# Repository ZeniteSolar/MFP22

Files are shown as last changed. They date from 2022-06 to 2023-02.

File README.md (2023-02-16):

# MFP19
**M**ódulo da **F**onte **P**rincipal 2019  
Embarcação Guarapuvu II  
Equipe Zênite Solar  

### Sobre

Este módulo é responsável por fornecer uma tensao fixa e estavel de 18V para alimentaçao dos modulos que estao na rede CAN

### Images
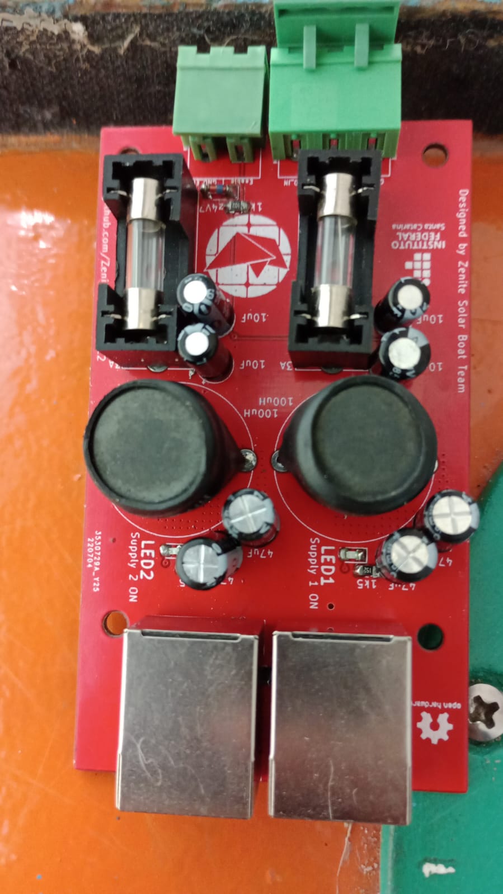
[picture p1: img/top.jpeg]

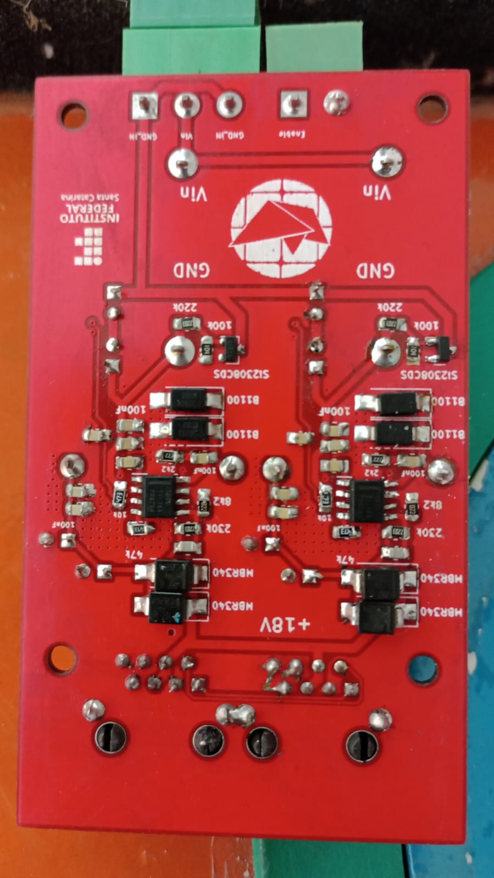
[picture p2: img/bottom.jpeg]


#### Requisitos e Abordagens
1. Fornecer tensao estavel de 18V 
    - Manter a tensao estavel independente da carga (até 3A)
    - Baixo ripple
2. Ser robusta
    - Nao queimar por curto-circuito
    - Nao queimar por sobre temperatura
    - Nao queimar por sobre-carga
    - Resistencia por ruido eletromagnetico e eletrico causados pelos componentes do sistema (motor,MCC...)
3. Eficiencia energetica.
    -Conversor estatico DC/DC chaveado
4. Facilitar o diagnóstico
    - Utilizar LEDs
    
**CI Ultilizado: Conversor LMR16030**
[Datasheet](https://www.ti.com/lit/ds/symlink/lmr16030.pdf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)

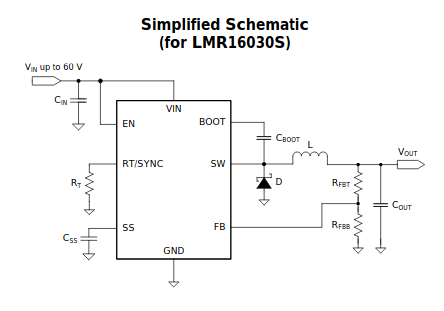
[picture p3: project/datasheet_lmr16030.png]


#### Projeto do Indutor

   -seleção do indutor de saida:



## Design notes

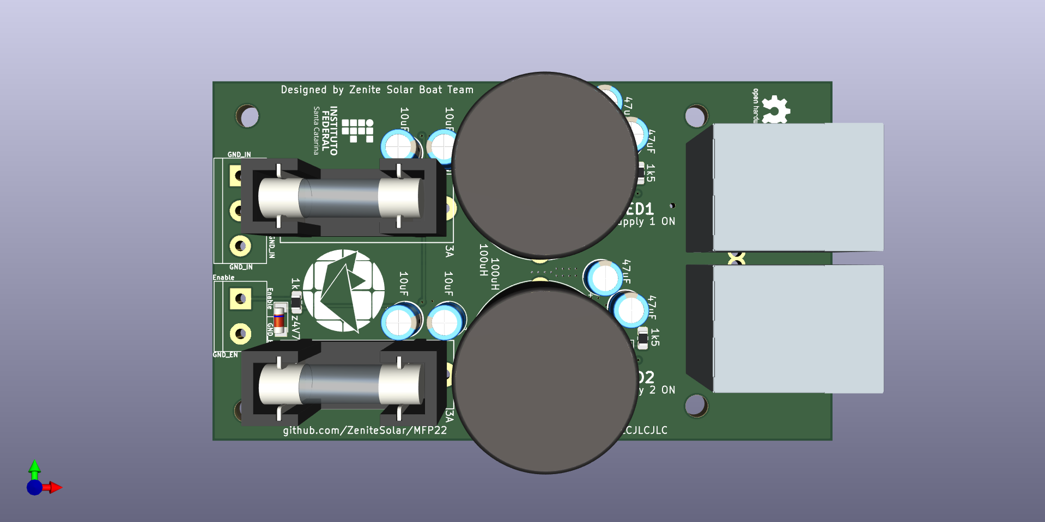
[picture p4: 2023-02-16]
3D/fonte_18V_top.png

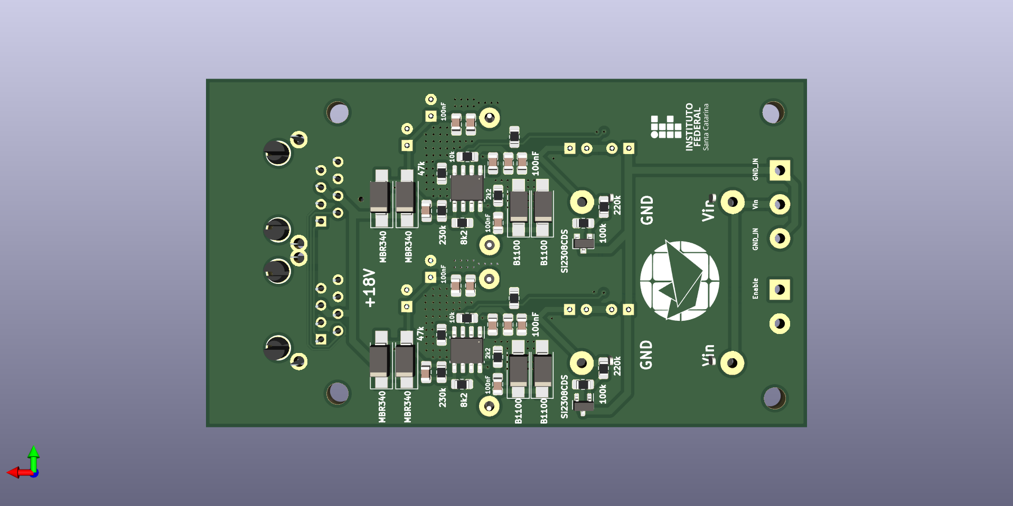
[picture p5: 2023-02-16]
3D/fonte_18V.png

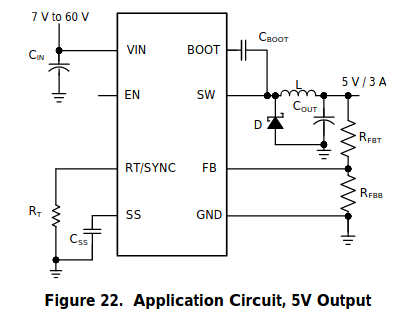
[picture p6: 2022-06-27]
project/ datasheet (Rev A) - lmr16030 pdf(1).png

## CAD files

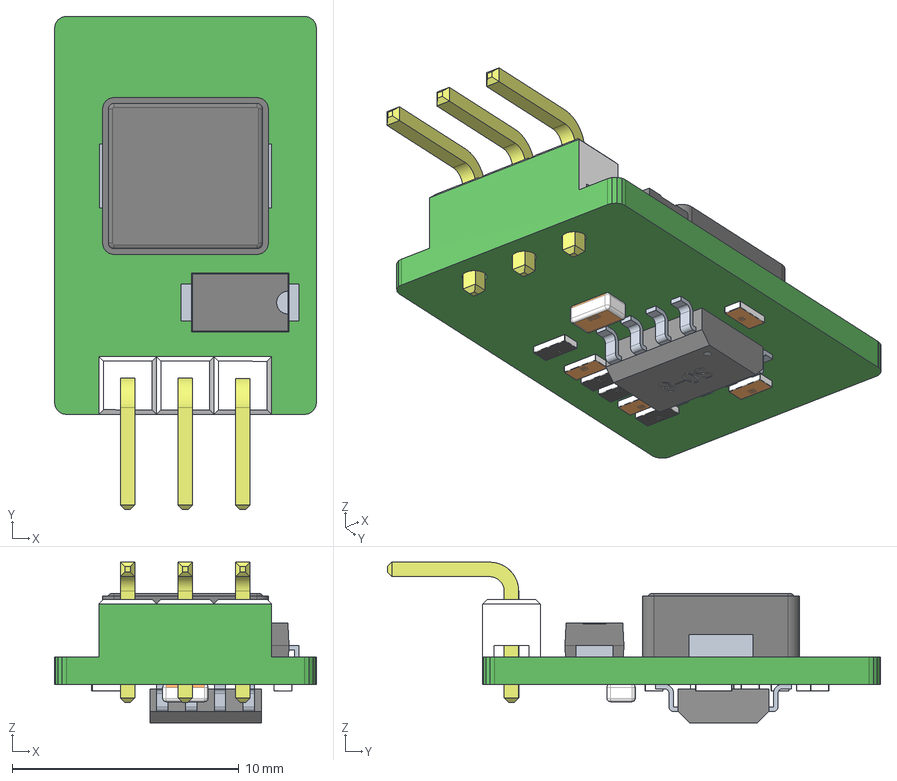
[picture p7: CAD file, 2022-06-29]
shapes3D/K78Lxx-1000R3.stp
11.5 x 21.7 x 7.08 mm

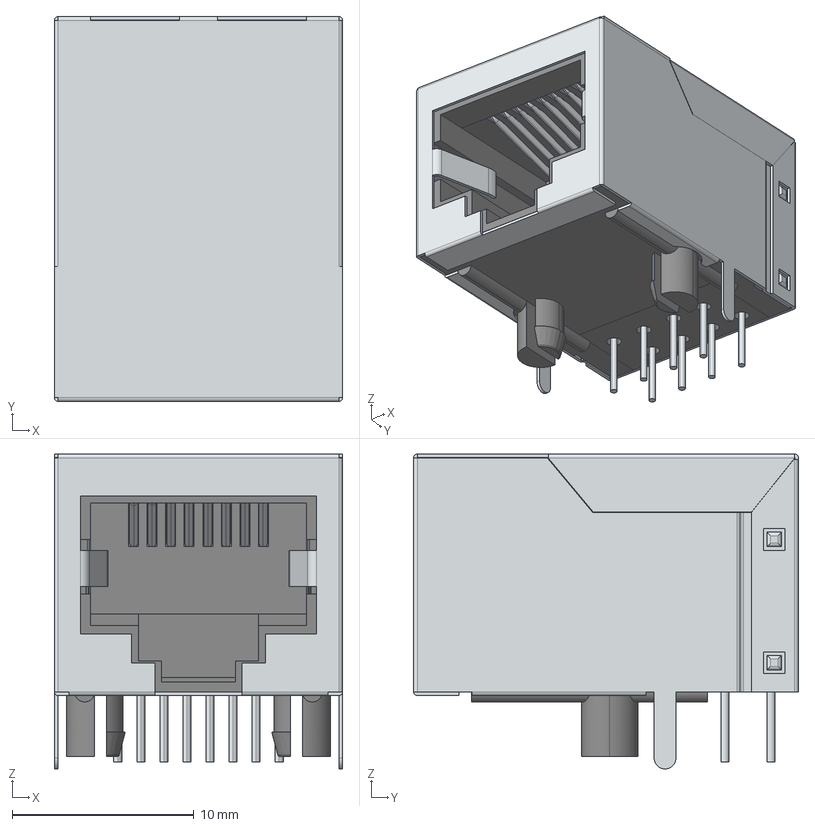
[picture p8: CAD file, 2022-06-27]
shapes3D/rj45.step
15.9 x 21.2 x 17.3 mm

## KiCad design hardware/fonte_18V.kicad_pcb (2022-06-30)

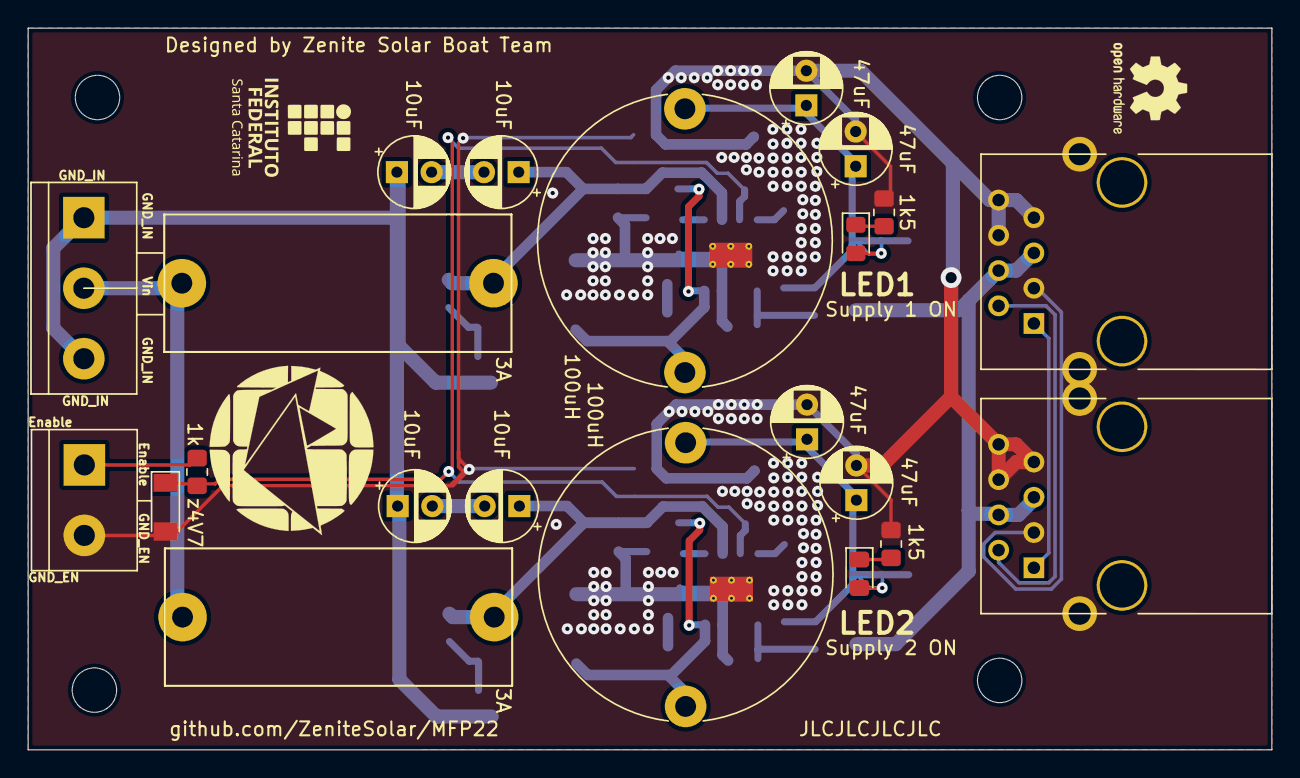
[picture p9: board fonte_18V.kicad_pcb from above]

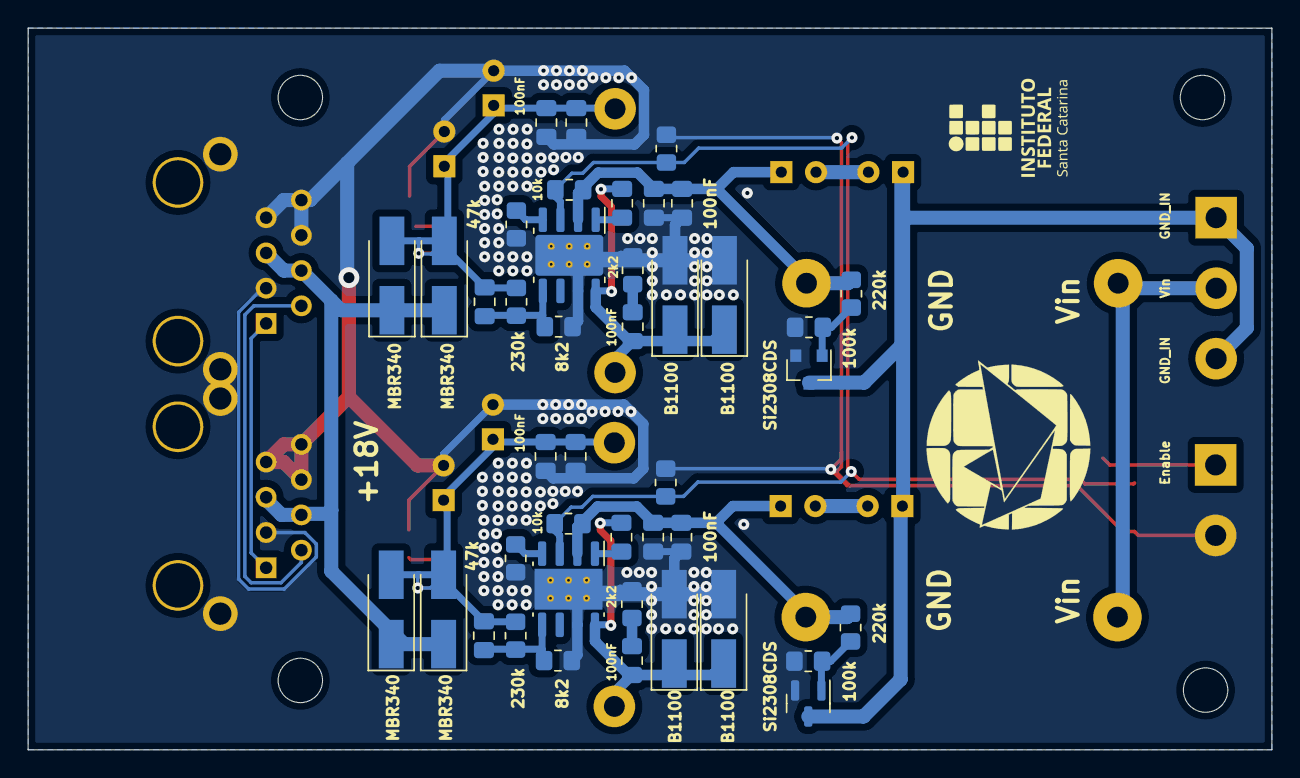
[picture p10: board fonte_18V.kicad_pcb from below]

Board: 2 copper layers, 89.6 x 52.0 mm, 73 parts (44 on the bottom side), 28 nets.

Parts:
CBoot1, CBoot301: 100nF; C_0805_2012Metric_Pad1.18x1.45mm_HandSolder
Cff1, Cff301: na; C_0805_2012Metric_Pad1.18x1.45mm_HandSolder
Ci1, Ci301: 10u; CP_Radial_D5.0mm_P2.50mm
Cie101, Cie301: 10u; CP_Radial_D5.0mm_P2.50mm
Cin2, Cin3, Cin301, Cin302: 100nF; C_0805_2012Metric_Pad1.18x1.45mm_HandSolder
Co1, Co2, Co301, Co302: 47u; CP_Radial_D5.0mm_P2.50mm
Co3, Co303: o.1u; C_0805_2012Metric_Pad1.18x1.45mm_HandSolder
Co4, Co304: 0.1u; C_0805_2012Metric_Pad1.18x1.45mm_HandSolder
Cs1, Cs301: 100n; C_0805_2012Metric_Pad1.18x1.45mm_HandSolder
D101: 4v7; D_MiniMELF
D102, D201, D303, D304: MBR340; D_SMA_Handsoldering
D103, D104, D301, D302: B1100; D_SMA_Handsoldering
F101, F301: Fuse; Fuse_Holder_5x20
H1, H2, H3, H4: MountingHole; MountingHole_3.2mm_M3
J101: IN; TerminalBlock_bornier-3_P5.08mm
J102: Conn_01x02; TerminalBlock_bornier-2_P5.08mm
J401, J402: RJ45_Shielded; RJ45_YH59_01
L1, L301: 100uH; L_Radial_D21.0mm_P19.00mm
LOGO101: Logo_Open_Hardware_Small; OSHW-Logo2_7.3x6mm_SilkScreen
Led1, Led101: LED; LED_0805_2012Metric_Pad1.15x1.40mm_HandSolder
Q1, Q301: Si2308CDS; SOT-23
R1, R305: 47k; R_0805_2012Metric_Pad1.20x1.40mm_HandSolder
R2: 1k; R_0805_2012Metric_Pad1.20x1.40mm_HandSolder
R3, R301: 220K; R_0805_2012Metric_Pad1.20x1.40mm_HandSolder
R4, R302: 100K; R_0805_2012Metric_Pad1.20x1.40mm_HandSolder
R5, R303: 10K; R_0805_2012Metric_Pad1.20x1.40mm_HandSolder
R6, R304: NA; R_0805_2012Metric_Pad1.20x1.40mm_HandSolder
RLed1, RLed101: 1k5; R_0805_2012Metric_Pad1.20x1.40mm_HandSolder
Rfbb1, Rfbb301: 8k2; R_0805_2012Metric_Pad1.20x1.40mm_HandSolder
Rfbt2, Rfbt301: 230k; R_0805_2012Metric_Pad1.20x1.40mm_HandSolder
Rs1, Rs301: 2k2; R_0805_2012Metric_Pad1.20x1.40mm_HandSolder
SYM101, SYM102: SYM_Flash_Small; symbol_logoZenite
SYM103, SYM104: SYM_Flash_Small; synbol_logoifsc
U1, U301: LMR16030; Texas_R-PDSO-G8_EP2.95x4.9mm_Mask2.4x3.1mm_ThermalVias

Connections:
/CAN/CAN_18V: D102.1 (K), D201.1 (K), D303.1 (K), D304.1 (K), J401.4, J401.5, J402.4, J402.5
/EN: D101.1 (K), R2.1, R5.1, R6.2, R303.1, R304.2, U1.3 (EN), U301.3 (EN)
/supply1/CAN_18V_DIODE: Cff1.1, Co1.1, Co2.1, Co3.1, Co4.1, D102.2 (A), D201.2 (A), L1.2, Led1.2 (A), Rfbt2.1
/supply1/Feedback: Cff1.2, Rfbb1.1, Rfbt2.2, U1.5 (FB)
/supply1/GND_IN: Cie101.1, Cie301.1, J101.1, J101.3, Q1.3 (D), Q301.3 (D)
/supply1/IN: F101.1, F301.1, J101.2
/supply1/snbr: Cs1.2, Rs1.1
/supply2/CAN_18V_DIODE: Cff301.1, Co301.1, Co302.1, Co303.1, Co304.1, D303.2 (A), D304.2 (A), L301.2, Led101.2 (A), Rfbt301.1
/supply2/Feedback: Cff301.2, Rfbb301.1, Rfbt301.2, U301.5 (FB)
/supply2/snbr: Cs301.2, Rs301.1
GND: Cin2.2, Cin3.2, Cin301.2, Cin302.2, Co1.2, Co2.2, Co3.2, Co4.2, Co301.2, Co302.2, Co303.2, Co304.2, D101.2 (A), D103.2 (A), D104.2 (A), D301.2 (A), D302.2 (A), J102.2, J401.3, J401.6, J401.7, J401.8, J401.SH, J402.3, J402.6, J402.7, J402.8, J402.SH, Q1.2 (S), Q301.2 (S), R1.2, R4.2, R6.1, R302.2, R304.1, R305.2, RLed1.2, RLed101.2, Rfbb1.2, Rfbb301.2, Rs1.2, Rs301.2, U1.7 (GND), U1.9 (Thermal_Pad), U301.7 (GND), U301.9 (Thermal_Pad)
unnamed: CBoot1.1, Cs1.1, D103.1 (K), D104.1 (K), L1.1, U1.8 (SW)
unnamed: CBoot1.2, U1.1 (BOOT)
unnamed: CBoot301.1, Cs301.1, D301.1 (K), D302.1 (K), L301.1, U301.8 (SW)
unnamed: CBoot301.2, U301.1 (BOOT)
unnamed: Ci1.1, Cin2.1, Cin3.1, F101.2, R3.1, R5.2, U1.2 (VIN)
unnamed: Ci1.2, Cie101.2
unnamed: Ci301.1, Cin301.1, Cin302.1, F301.2, R301.1, R303.2, U301.2 (VIN)
unnamed: Ci301.2, Cie301.2
unnamed: J102.1, R2.2
unnamed: J401.1, J402.1
unnamed: J401.2, J402.2
unnamed: Led1.1 (K), RLed1.1
unnamed: Led101.1 (K), RLed101.1
unnamed: Q1.1 (G), R3.2, R4.1
unnamed: Q301.1 (G), R301.2, R302.1
unnamed: R1.1, U1.4 (RT/SYNC)
unnamed: R305.1, U301.4 (RT/SYNC)

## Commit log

2022-06-27 copy MFP19
    [RJ45.kicad_sch, Supply1.kicad_sch, canbus_connector.sch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]
2022-06-27 Organize schematics for better visualization
    [fonte_18V.kicad_sch]
2022-06-29 Duplicate fonts for redundancy and initialized layout
    [CAN.kicad_sch, fonte_18V.kicad_pcb, fonte_18V.kicad_sch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]
2022-06-29 almost finished
    [CAN.kicad_sch, fonte_18V.kicad_pcb, fonte_18V.kicad_sch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]
2022-06-29 run DRC and turn invisible reference designators
    [fonte_18V.kicad_pcb]
2022-06-29 Add silkscreen for connectors and author label
    [fonte_18V.kicad_pcb]
2022-06-29 Adjusted silkscreen and fixed RDC errors
    [K78Lxx-1000R3.stp, fonte_18V.kicad_pcb, fonte_18V.kicad_sch]
2022-06-29 removed duplicated case-insensitive file
    [Supply1.kicad_sch]
2022-06-29 resize board
    [fonte_18V.kicad_pcb]
2022-06-30 Silkscreen updated with JLC. Finished.
    [fonte_18V.kicad_pcb]
2023-02-16 Organize repo, and update README
    [CAN.kicad_sch, RJ45.kicad_sch, canbus_connector.sch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]
